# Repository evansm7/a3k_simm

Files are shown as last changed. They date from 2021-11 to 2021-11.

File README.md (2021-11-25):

# Acorn A3000 4MB SIMM adapter board

25 Nov 2021

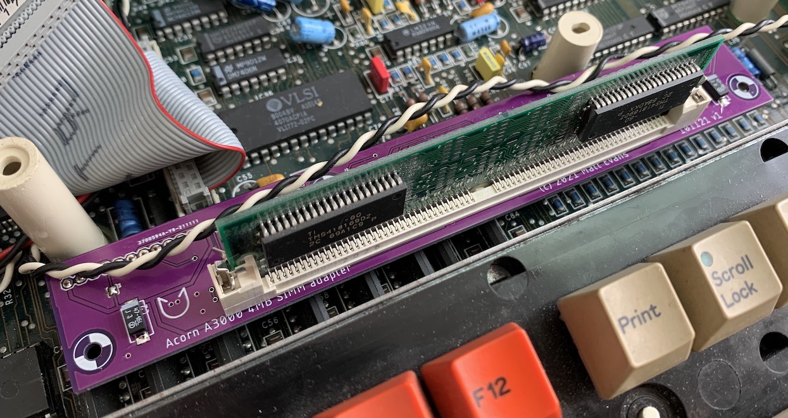
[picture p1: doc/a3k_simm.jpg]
A3000 with SIMM adapter installed


This board allows an Acorn A3000 computer to be upgraded to 4MB of RAM using a (still) common 4MB 72-pin SIMM.

Designed in Eagle.  Schematic [here](doc/simm_adapter_schematic.pdf), board layout [here](doc/simm_adapter_board.pdf).

Snazzy purple PCB c/o JLCPCB's 2-layer PCB service.

## SIMM compatibility

SIMMs are constructed with one bank (RAS0/RAS2 strobes) or two banks (RAS0-RAS3 strobes).

You will require a non-parity FPM or EDO 4MB SIMM with *one* bank.  Speed shouldn't matter, 70ns is fine.

Tested with a SIMM containing 2x TMS418169DZ 60ns EDO parts.

Ideally, look out for a SIMM with two chips, on one side.  Typically two-bank SIMMs have chips on both sides (but this is just a rule of thumb).

Because the unused RAS1/RAS3 strobes are tied inactive, you may find an 8MB dual-bank SIMM can be used with one (4MB) bank active, but this has not been tested.  A parity SIMM should also work (though the parity data lines are floating, which might not be great).  Again, untested.

Also, try to find a SIMM as short as possible, to avoid crashing into the case.  In extreme cases, the long pin headers on the A3000 motherboard could be trimmed or replaced...

## Construction

You will need:

   * 3x 0.1" 1x20 pin header sockets
   * 1x 72 pin vertical SIMM socket, such as a _TE Connectivity 5822021-4_
   * 2x Tantalum/SMT electrolytic capacitors.  Exact value isn't too important*.  10uF, 47uF, something like that. 

*: I noticed my SIMM doesn't have any decoupling on it whatsoever (but has footprints).  Cheeep.  You might want to add some more caps in the 0.1-1uF range, if this is the case.

A hole is provided in the middle for a bracket (not provided) that can attach to the nearby motherboard mounting hole, for stability.

## Licence

No warranty is provided, and this work is used at your own risk.  

Licenced as CC BY-SA 3.0

Copyright 2021 Matt Evans

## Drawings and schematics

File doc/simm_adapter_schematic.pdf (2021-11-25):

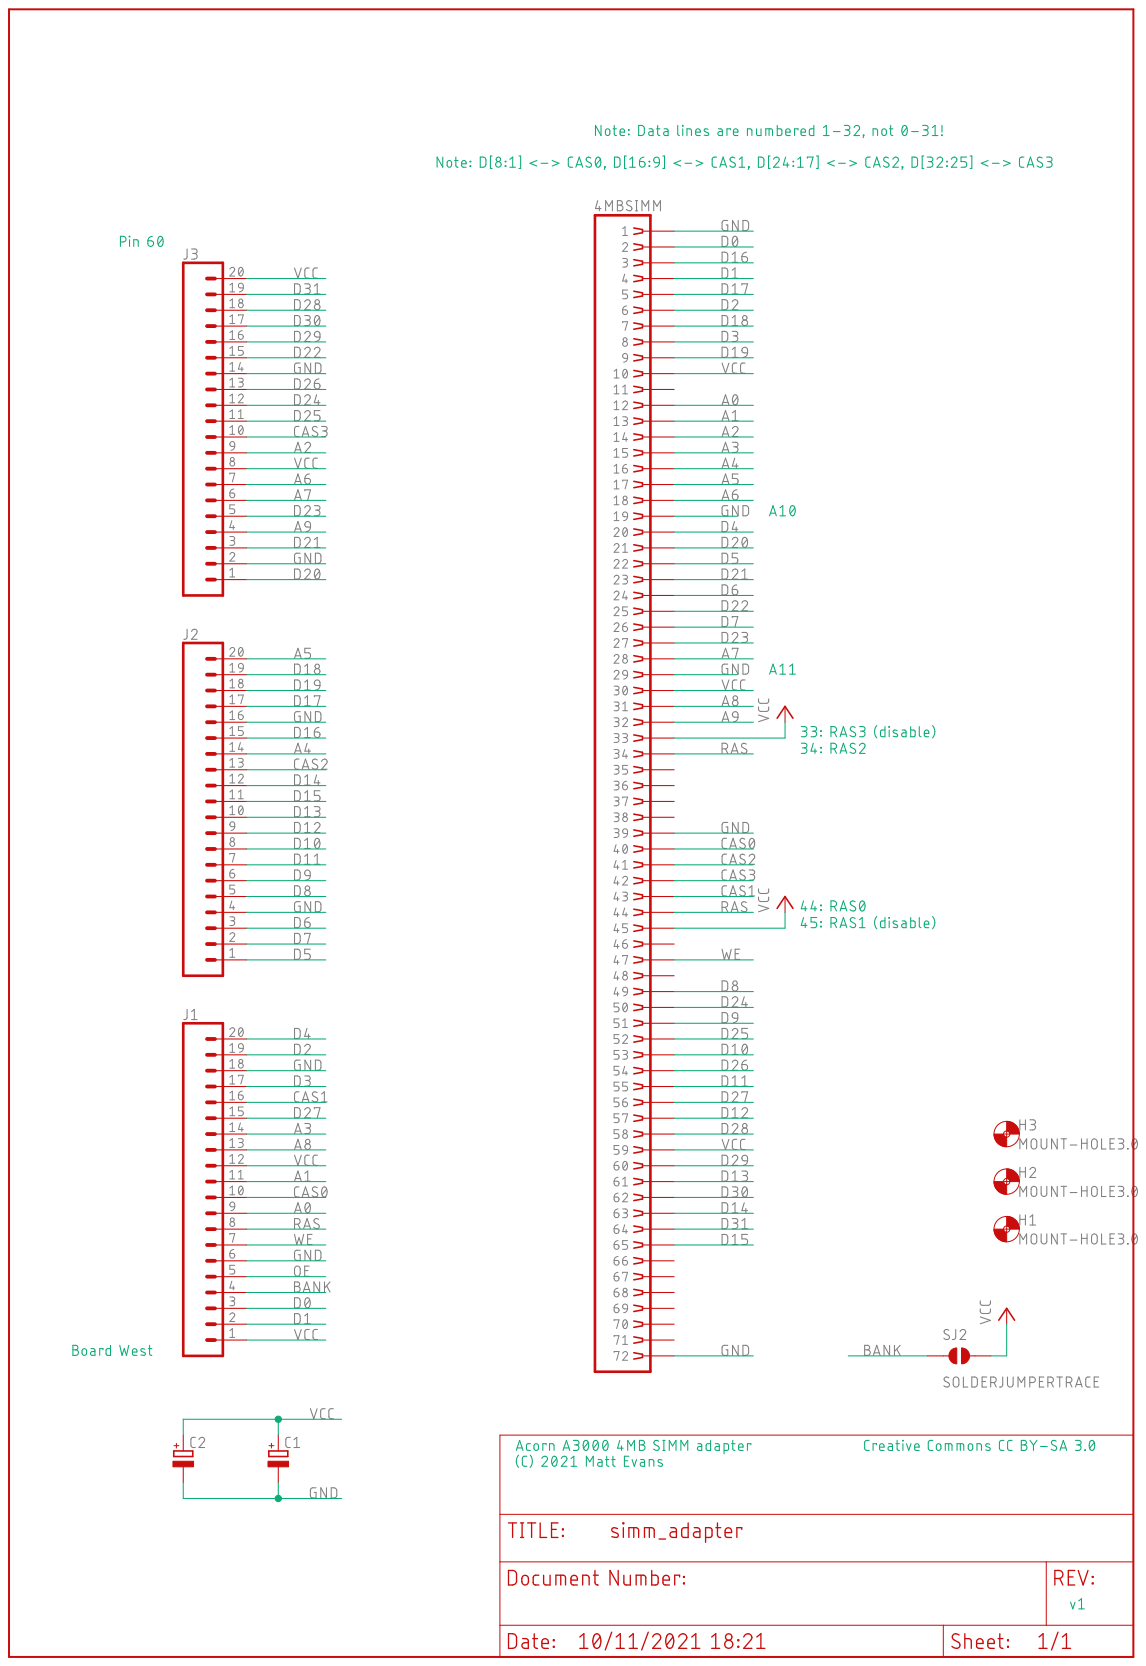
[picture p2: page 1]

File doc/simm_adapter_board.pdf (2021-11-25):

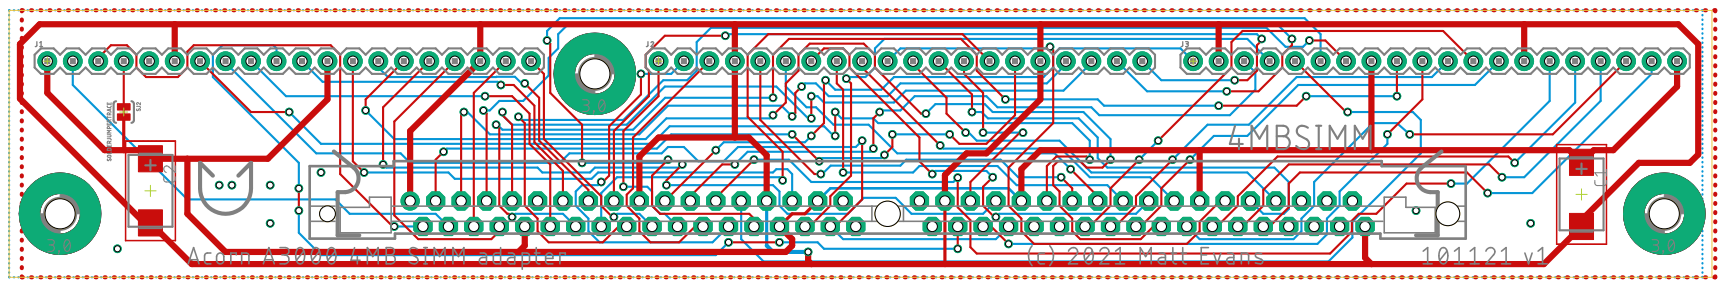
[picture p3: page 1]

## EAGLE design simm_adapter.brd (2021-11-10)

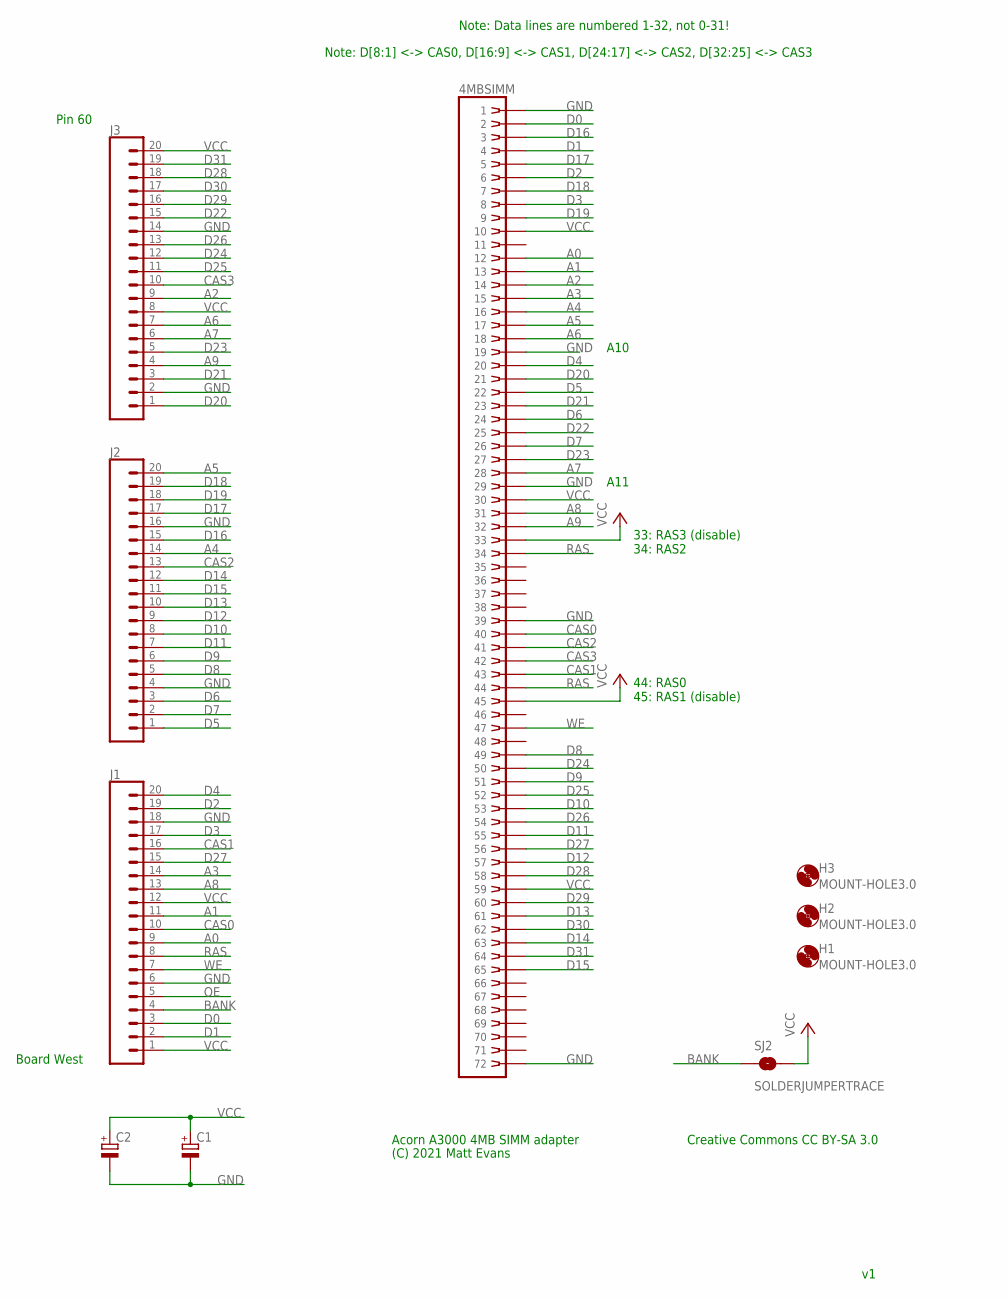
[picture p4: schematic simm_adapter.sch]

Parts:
4MBSIMM: SIMM72; 73826962
C1, C2: CPOL-EUCT7343; CT7343
H1, H2, H3: MOUNT-HOLE3.0; 3,0
J1, J2, J3: CONN_20; 1X20
SJ2: SOLDERJUMPERTRACE; SJ_2S-TRACE

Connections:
A0: 4MBSIMM.12, J1.9
A1: 4MBSIMM.13, J1.11
A2: 4MBSIMM.14, J3.9
A3: 4MBSIMM.15, J1.14
A4: 4MBSIMM.16, J2.14
A5: 4MBSIMM.17, J2.20
A6: 4MBSIMM.18, J3.7
A7: 4MBSIMM.28, J3.6
A8: 4MBSIMM.31, J1.13
A9: 4MBSIMM.32, J3.4
BANK: J1.4, SJ2.1
CAS0: 4MBSIMM.40, J1.10
CAS1: 4MBSIMM.43, J1.16
CAS2: 4MBSIMM.41, J2.13
CAS3: 4MBSIMM.42, J3.10
D0: 4MBSIMM.2, J1.3
D1: 4MBSIMM.4, J1.2
D2: 4MBSIMM.6, J1.19
D3: 4MBSIMM.8, J1.17
D4: 4MBSIMM.20, J1.20
D5: 4MBSIMM.22, J2.1
D6: 4MBSIMM.24, J2.3
D7: 4MBSIMM.26, J2.2
D8: 4MBSIMM.49, J2.5
D9: 4MBSIMM.51, J2.6
D10: 4MBSIMM.53, J2.8
D11: 4MBSIMM.55, J2.7
D12: 4MBSIMM.57, J2.9
D13: 4MBSIMM.61, J2.10
D14: 4MBSIMM.63, J2.12
D15: 4MBSIMM.65, J2.11
D16: 4MBSIMM.3, J2.15
D17: 4MBSIMM.5, J2.17
D18: 4MBSIMM.7, J2.19
D19: 4MBSIMM.9, J2.18
D20: 4MBSIMM.21, J3.1
D21: 4MBSIMM.23, J3.3
D22: 4MBSIMM.25, J3.15
D23: 4MBSIMM.27, J3.5
D24: 4MBSIMM.50, J3.12
D25: 4MBSIMM.52, J3.11
D26: 4MBSIMM.54, J3.13
D27: 4MBSIMM.56, J1.15
D28: 4MBSIMM.58, J3.18
D29: 4MBSIMM.60, J3.16
D30: 4MBSIMM.62, J3.17
D31: 4MBSIMM.64, J3.19
GND: 4MBSIMM.1, 4MBSIMM.19, 4MBSIMM.29, 4MBSIMM.39, 4MBSIMM.72, C1.-, C2.-, J1.6, J1.18, J2.4, J2.16, J3.2, J3.14
OE: J1.5
RAS: 4MBSIMM.34, 4MBSIMM.44, J1.8
VCC: 4MBSIMM.10, 4MBSIMM.30, 4MBSIMM.33, 4MBSIMM.45, 4MBSIMM.59, C1.+, C2.+, J1.1, J1.12, J3.8, J3.20, SJ2.2
WE: 4MBSIMM.47, J1.7

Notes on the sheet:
Pin 60
Board West
44: RAS0 45: RAS1 (disable)
33: RAS3 (disable) 34: RAS2
Note: Data lines are numbered 1-32, not 0-31!
Note: D[8:1] <-> CAS0, D[16:9] <-> CAS1, D[24:17] <-> CAS2, D[32:25] <-> CAS3
A10
A11
Acorn A3000 4MB SIMM adapter
(C) 2021 Matt Evans
Creative Commons CC BY-SA 3.0

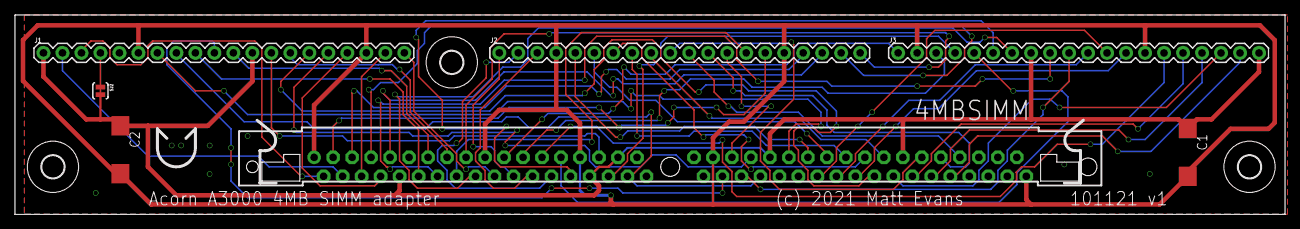
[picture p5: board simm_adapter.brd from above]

Board: 2 copper layers, 169.8 x 26.7 mm, 10 parts (0 on the bottom side), 51 nets.

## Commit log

2021-11-10 v1 of SIMM adapter
    Fully routed (partially using messy autorouter), passes JLCPCB 2L DRC.
    [simm_adapter.brd, simm_adapter.sch]
2021-11-25 Add v1 gerber files
    [simm_adapter.GBL, simm_adapter.GBO, simm_adapter.GBP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]
2021-11-25 Add board/schematic PDFs

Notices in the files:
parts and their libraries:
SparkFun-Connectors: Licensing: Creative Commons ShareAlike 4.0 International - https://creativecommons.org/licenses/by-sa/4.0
